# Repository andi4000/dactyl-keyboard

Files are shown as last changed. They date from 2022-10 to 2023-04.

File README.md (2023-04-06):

# Andi4000 6x7 Dactyl-ManuForm Fork

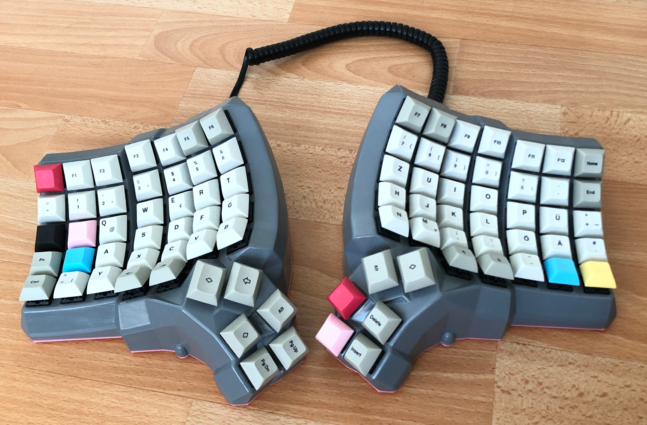
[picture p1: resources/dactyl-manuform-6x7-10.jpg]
Dactyl Manuform 6x7 ISO-DE


Pictured is the finished build with (close to) ISO-DE Layout, with DSA Profile
Keycaps from YMDK, and some blank 1U keycaps.

[Click here](#firmware) for the QMK Firmware for this layout.

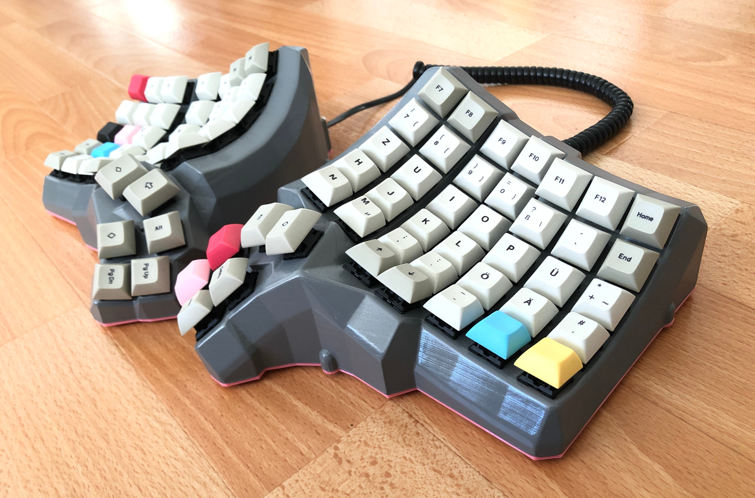
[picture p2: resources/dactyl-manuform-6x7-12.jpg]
Dactyl Manuform 6x7 ISO-DE


## TODO
- reduce heat insert diameter

## Differences
- 6x7 Layout. Coming from TKL ISO Layout, I am too lazy to use layers and learn
  a new layout. I also need dedicated F-Keys.
- No Wire Post
- Mount for [Delock Cable USB 2.0 Micro-B Female Panel-Mount](https://www.delock.com/produkt/85245/merkmale.html)
- Flipped RJ9 mount, so that the cable clip will end up on the upper side
- New Promicro Mount

See [right.stl](things/right.stl) for preview.

## FDM 3D-Print Setup
- I use Ultimaker Cura (v5.1.1) as slicer, with following settings
    - 0.2mm layer height
    - (**Important**) Support Structure: Tree --> extremely easier to remove
      compared to normal
    - 10% Infill
    - 10mm Brim
- Printer: stock Sovol SV02 with heated bed, Esun PLA with 205°C nozzle temp 
  and 60°C bed temp.
- PVA glue (UHU Stic) applied to the bed, especially on the brim and sidewalls
  area because they tend to warp, which is a common (big) print issue.
- How to know where the brim and side wall will go? Start print and stop when
  the outer brim is printed. That would be the boundaries. I applied generous
  amount of PVA glue there.
- Once the print reaches ca. Z=10mm, if warping is not present, print is more
  likely to be succeeded, w.r.t. warping.
- Be careful on removing support structure around the Promicro mount. Make sure
  you know how it should look like without the support. See `right.stl`.

## Assembly
For 6x7 you need following items:
- 86 Cherry-MX (or compatible) Switches
- 82 1U Keycaps. I use DSA profile keycaps. Cherry profile are reported to also
  work.
- 4 1U or 1.25U Keycaps for the upper thumb
- M3 Heat Inserts, at least 10 pcs.
- M3x5 countersink screws, at least 10 pcs.

Wired and (almost fully) assembled left side:
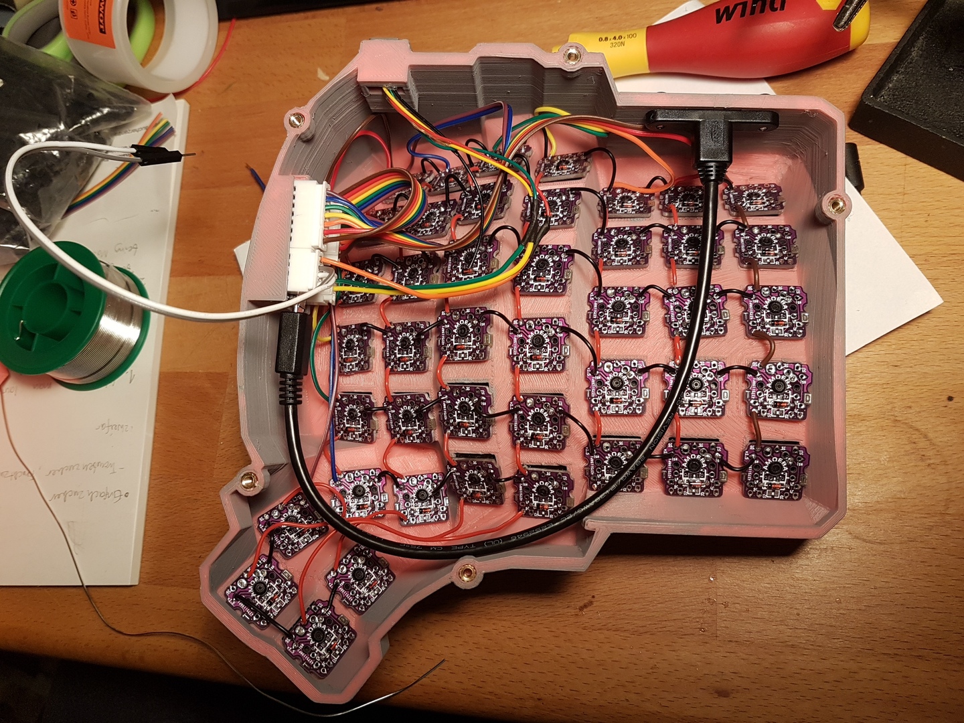
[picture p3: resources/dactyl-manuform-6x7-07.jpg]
wired left side


What really helped during the assembly was to have and use following:
- [Amoeba single-switch PCB](https://deskthority.net/viewtopic.php?t=11420) from
  a local vendor. I bought 100 pcs. with some spares just in case I messed up.
- A good soldering iron. I used [Ersa C25 25W](https://www.ersa-shop.com/ersa-l%C3%B6tkolben-multitip-230v-p-2787.html).
  I went through two cheap soldering irons, both end up with broken tip and
  subpar results. Also a metal solder tip cleaner.
- Single-core jumper wires. I used wires with 0.2 sq. mm cross section. It's
  stiff compared to wires with multi-core, which make the PCBs to stay in place
  before soldering.
- Multimeter to do continuity check. Cheap one will do.

Additionally I also use XH-Type connector at the ProMicro as idiot-proofing.

## Build Photos
<details>
<summary>Finished 24h-long print.</summary>
"Tree" support structure really makes removing supports easier.

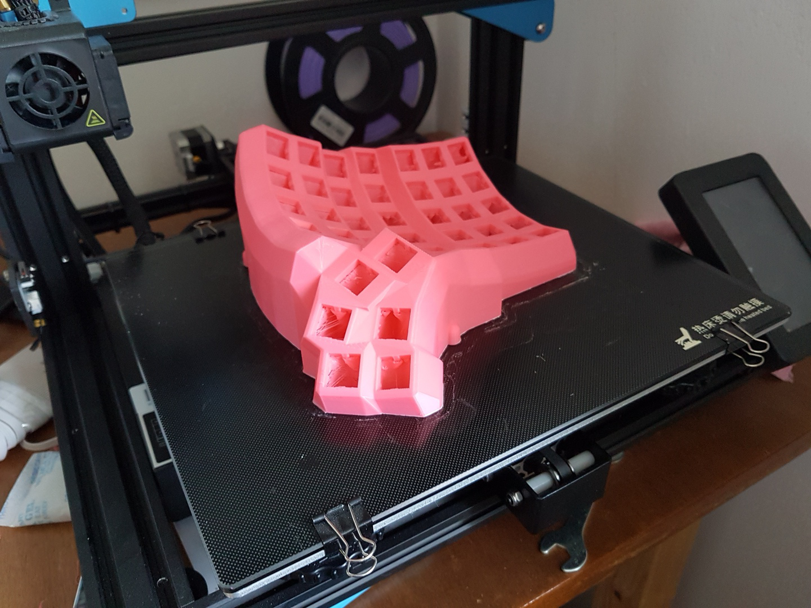
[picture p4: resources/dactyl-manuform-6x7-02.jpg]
fresh out of the oven

</details>

<details>
<summary>Sanded, primered, painted, clear coat.</summary>

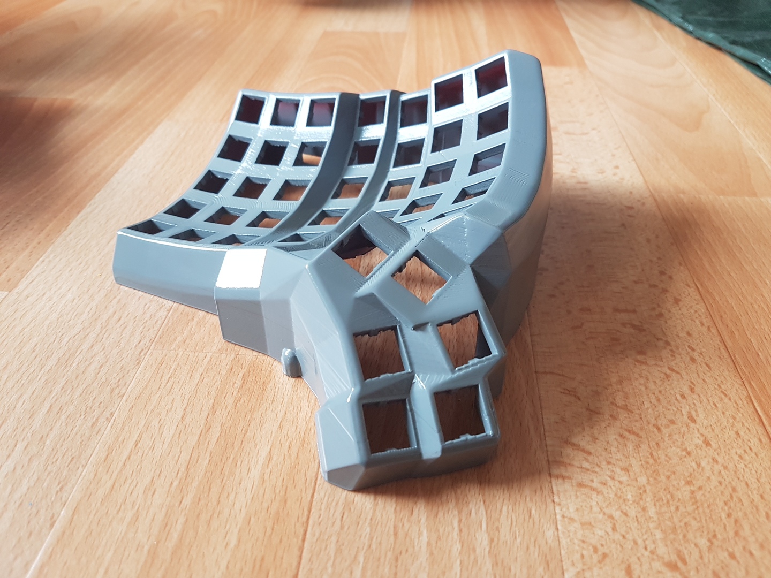
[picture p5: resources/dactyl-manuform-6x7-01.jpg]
sanded and painted

</details>

<details>
<summary>Continuity check after soldering diodes.</summary>
Easier if you do this in batch of e.g. 10 PCBs

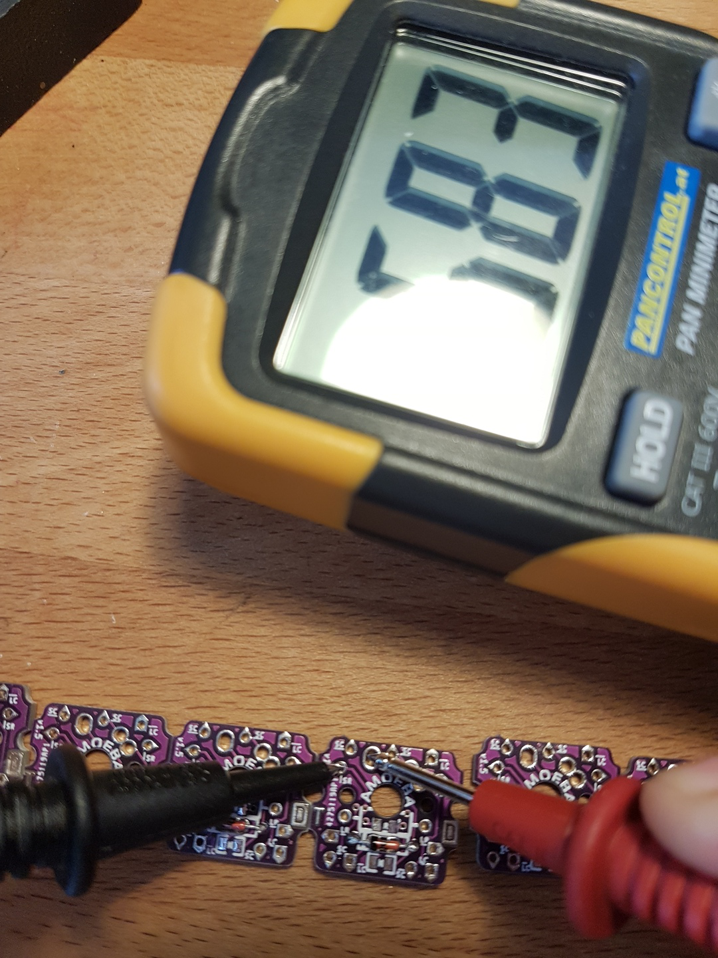
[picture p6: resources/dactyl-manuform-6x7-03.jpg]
continuity check

</details>

<details>
<summary>Wiring harness with Amoeba PCB for the left side.</summary>
With XH-Connectors for the rows and columns

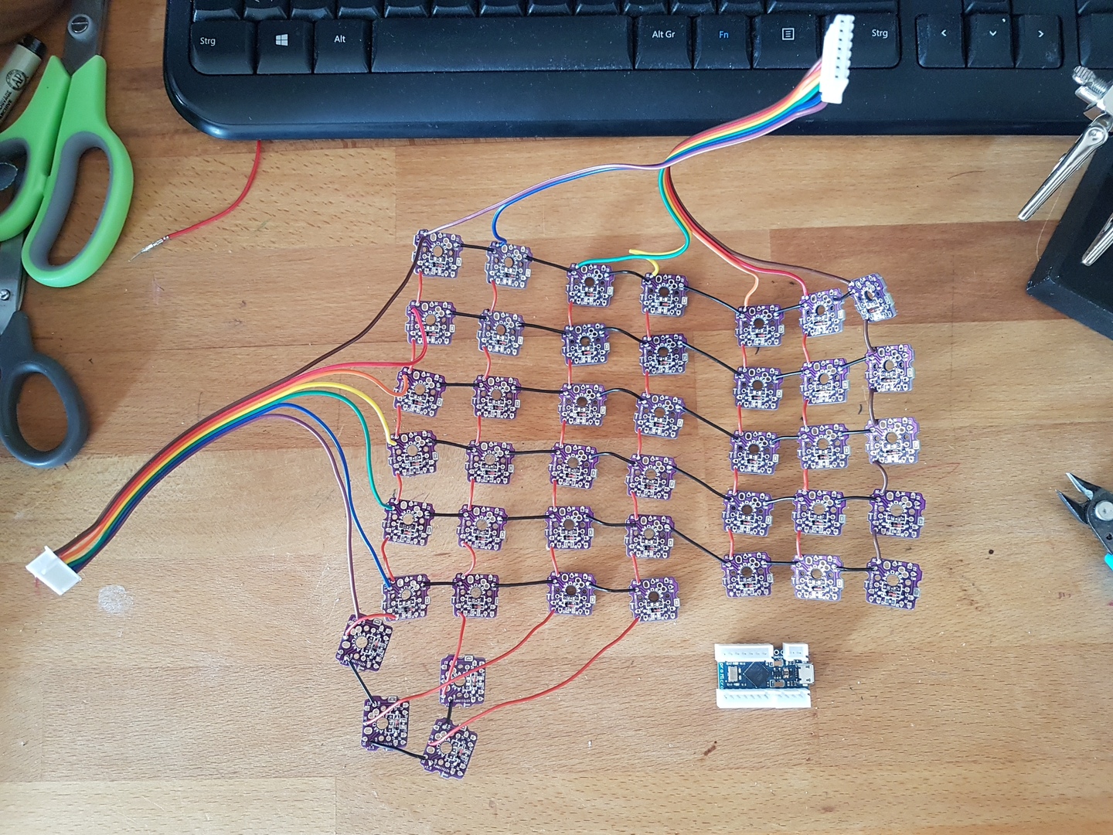
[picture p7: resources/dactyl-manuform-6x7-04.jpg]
wiring left with XH connector


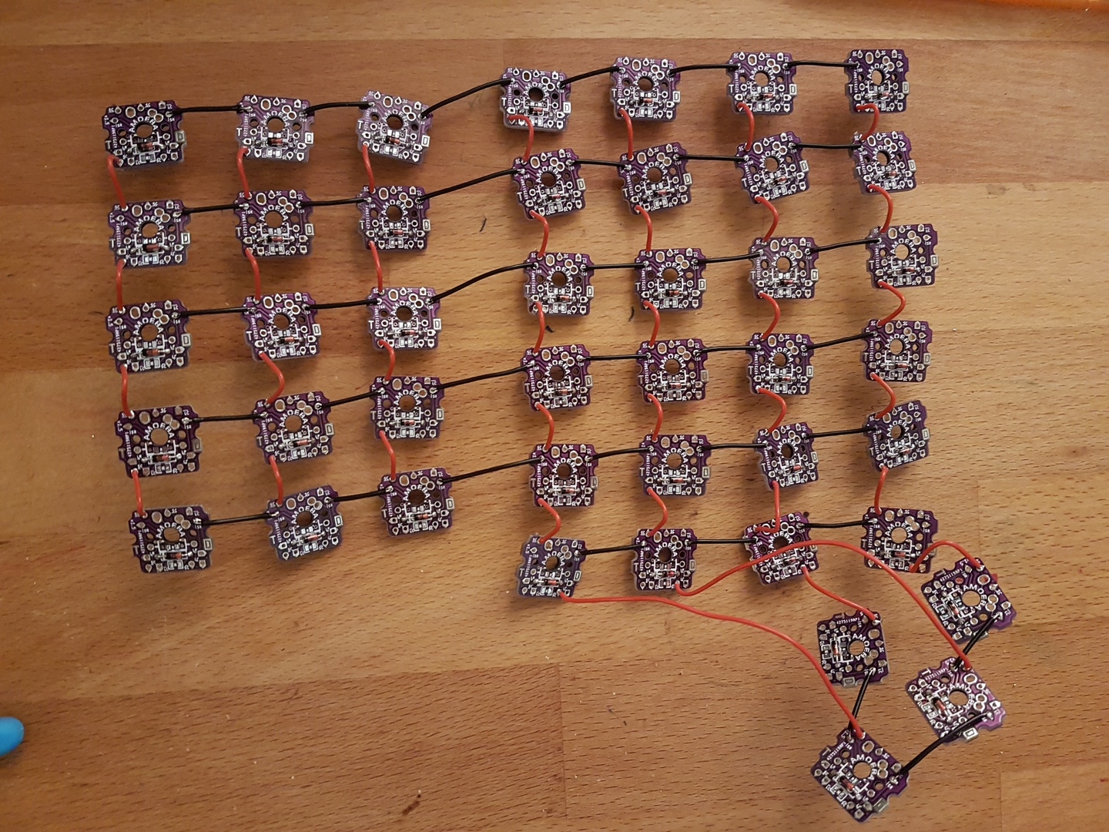
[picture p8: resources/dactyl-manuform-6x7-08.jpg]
wiring left

</details>

<details>
<summary>Mounted wiring harness for the left side.</summary>
Soldering the top left (the deepest point) was really difficult.
I found it to be easier to first remove the switch, put PCB on position,
then carefully insert the switch back.

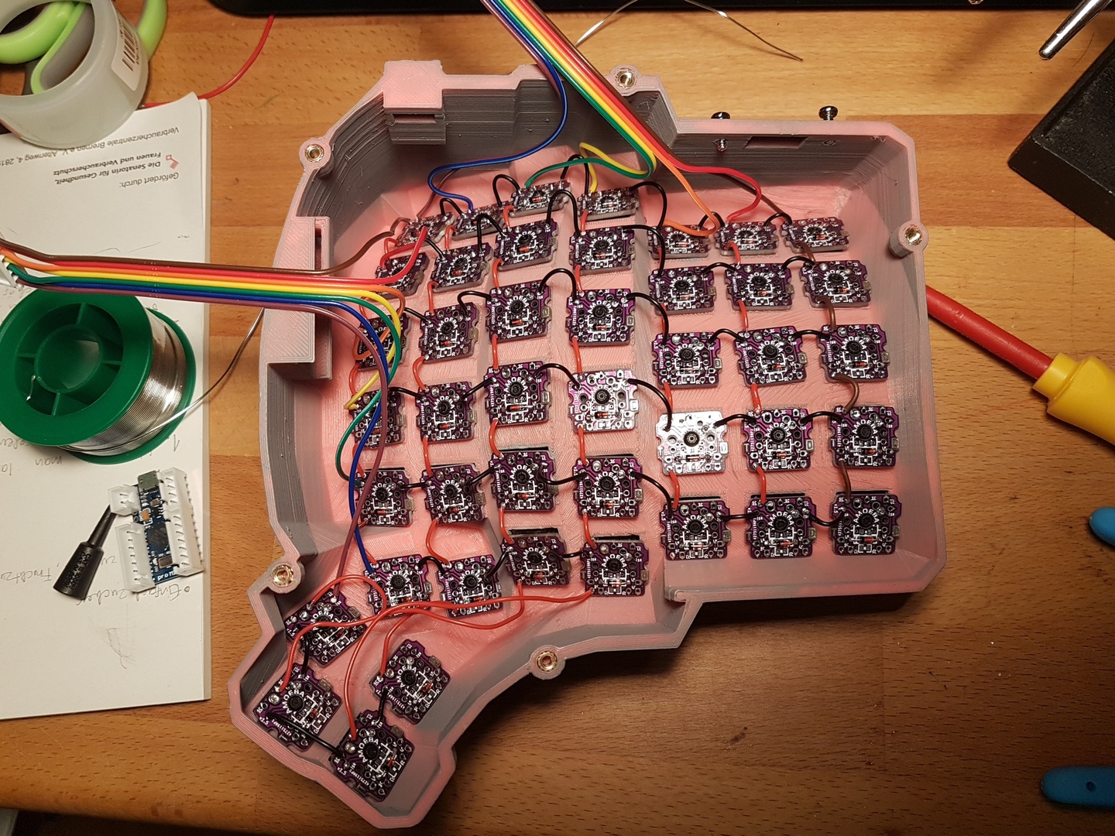
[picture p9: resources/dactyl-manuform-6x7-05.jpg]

</details>

<details>
<summary>Close up of the mounted wiring harness for the left side.</summary>
Bokeh!

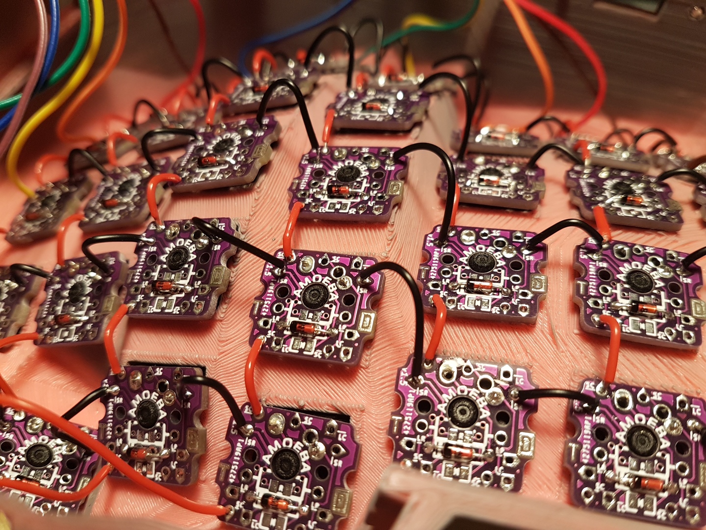
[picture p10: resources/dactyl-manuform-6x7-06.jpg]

</details>

<details>
<summary>Wiring harness for the right side.</summary>
It was a very sunny day

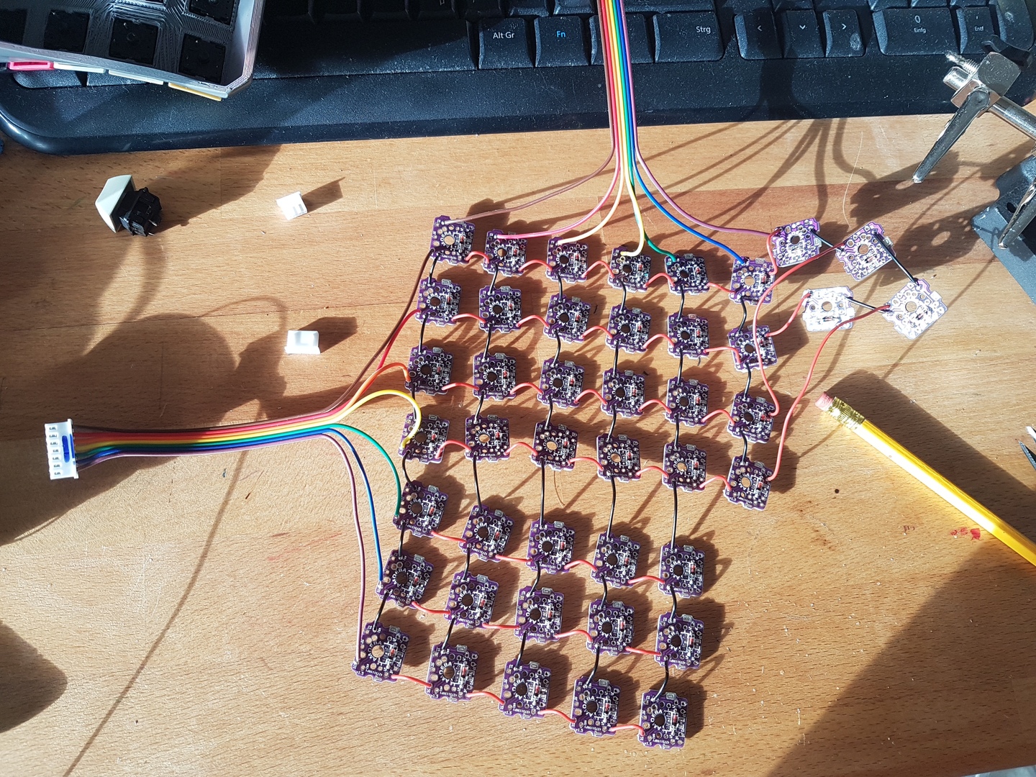
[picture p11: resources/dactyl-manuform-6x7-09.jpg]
wiring right

</details>

<details>
<summary>Finished!</summary>

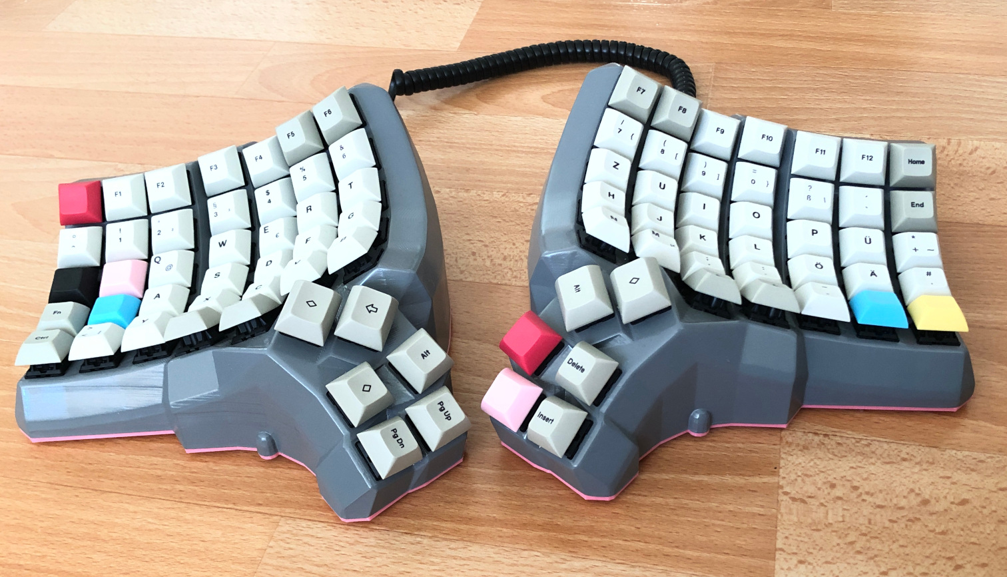
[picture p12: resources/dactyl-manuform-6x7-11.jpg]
Done

</details>

## Firmware

For firmware flashing please refer to this page on QMK: [qmk_firmware for 6x7 Dactyl Manuform ISO-DE](https://github.com/qmk/qmk_firmware/tree/master/keyboards/handwired/dactyl_manuform/6x7/keymaps/iso-de)

## License

The source code for generating the models (everything excluding the [things/](things/) and [resources/](resources/) directories is distributed under the [GNU AFFERO GENERAL PUBLIC LICENSE Version 3](LICENSE).  The generated models and PCB designs are distributed under the [Creative Commons Attribution-NonCommercial-ShareAlike License Version 3.0](LICENSE-models).

## Original Readme
[README.orig.md](README.orig.md)

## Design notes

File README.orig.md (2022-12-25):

# The Dactyl-ManuForm Keyboard
This is a fork of the [Dactyl](https://github.com/adereth/dactyl-keyboard), a parameterized, split-hand, concave, columnar, ergonomic keyboard.

Imgur

The main change is that the thumb cluster was adapted from the [ManuForm keyboard](https://github.com/jeffgran/ManuForm) ([geekhack](https://geekhack.org/index.php?topic=46015.0)). The walls were changed to just drop to the floor. The keyboard is paramaterized to allow adjusting the following: 

* Rows: 4 - 6 
* Columns: 5 and up
* Row curvature
* Column curvature
* Row tilt (tenting)
* Column tilt
* Column offsets
* Height

I built a 4x5 version (40% size) for myself. The default has a bit more tenting than the Dactyl. See the following model files for configurations that may be most common:

* [40% size, (4x5)](https://github.com/tshort/dactyl-keyboard/blob/master/things/right-4x5.stl)
* [60% size, (5x6)](https://github.com/tshort/dactyl-keyboard/blob/master/things/right-5x6.stl)

## Assembly

### Generating a Design

**Setting up the Clojure environment**
* [Install the Clojure runtime](https://clojure.org)
* [Install the Leiningen project manager](http://leiningen.org/)
* [Install OpenSCAD](http://www.openscad.org/)

**Generating the design**
* Run `lein repl`
* Load the file `(load-file "src/dactyl_keyboard/dactyl.clj")`
* This will regenerate the `things/*.scad` files
* Use OpenSCAD to open a `.scad` file.
* Make changes to design, repeat `load-file`, OpenSCAD will watch for changes and rerender.
* When done, use OpenSCAD to export STL files

**Tips**
* [Some other ways to evaluate the clojure design file](http://stackoverflow.com/a/28213489)
* [Example designing with clojure](http://adereth.github.io/blog/2014/04/09/3d-printing-with-clojure/)

### Printing
Pregenerated STL files are available in the [things/](things/) directory. 
When a model is generated, it also generates a `.scad` model for a bottom plate. 
This can be exported to a DXF file in OpenSCAD.
The [things/](things/) directory also has DXF files for the bottom plate.
When laser cut, some of the inside cuts will need to be removed. 

This model can be tricky to print. 
It's wide, so I've had problems with PLA on a Makerbot with edges warping. 
This can cause the printer to think its head is jammed. 
Even if it successfully prints, warping can cause problems. 
On one print, the RJ-9 holder was squished, so I had to cut down my connector to fit.

If printed at Shapeways or other professional shops, I would not expect such problems. 

### Thingiverse

[The 4x5 STL left/right pair](https://www.thingiverse.com/thing:2349390) from the [things/](things/) directory is in the thingiverse for public printing

### Wiring

Here are materials I used for wiring.

* Two Arduino Pro Micros
* [Heat-set inserts](https://www.mcmaster.com/#94180a331/=16yfrx1)
* [M3 wafer-head screws, 5mm](http://www.metricscrews.us/index.php?main_page=product_info&cPath=155_185&products_id=455)
* [Copper tape](https://www.amazon.com/gp/product/B009KB86BU)
* [#32 magnet wire](https://www.amazon.com/gp/product/B00LV909HI)
* [#30 wire](https://www.amazon.com/gp/product/B00GWFECWO)
* [3-mm cast acrylic](http://www.mcmaster.com/#acrylic/=144mfom)
* [Veroboard stripboard](https://www.amazon.com/gp/product/B008CPVMMU)
* [1N4148 diodes](https://www.amazon.com/gp/product/B00LQPY0Y0)
* [Female RJ-9 connectors](https://www.amazon.com/gp/product/B01HU7BVDU/)

I wired one half using the traditional approach of using the legs of a diode to form the row connections. 
(I'm not great at soldering, so this was challenging for me.)
For this side, I used magnet wire to wire columns. That worked okay. 
The magnet wire is small enough, it wants to move around, and it's hard to tell if you have a good connection.

Imgur

For another half, I used stripboard for the row connections. 
This allowed me to presolder all of the diodes. 
Then, I hot-glued this in place and finished the soldering of the other diode ends. 
I like this approach quite a lot. 
Connections for the diodes were much easier with one end fixed down. 
On this half, I also used copper tape to connect columns. 
This worked a bit better than the magnet wire for me. 
For a future version, I may try just bare tinned copper wire for columns (something like #20). 
With the stripboard, it's pretty easy keeping row and column connections separate.

Imgur

Note that a telephone handset cable has leads that are reversed, so take this into account when connecting these leads to the controller.

The 3D printed part is the main keyboard. 
You can attach a bottom plate with screws. 
The case has holes for heat-set inserts designed to hold 3- to 6-mm long M3 screws. 
Then, I used wafer-head screws to connect a bottom plate. 
If wires aren't dangling, a bottom plate may not be needed. 
You need something on the bottom to keep the keyboard from sliding around. 
Without a plate, you could use a rubber pad, or you could dip the bottom of the keyboard in PlastiDip.

For more photos of the first complete wiring of v0.4, see [Imgur](http://imgur.com/a/v9eIO).

This is how the rows/columns wire to the keys and the ProMicro
Wire Diagram

#### Alternative row-driven wiring diagram for ProMicro:

NOTE: you also make sure the firmware is set up correctly (ex: change row pins with col pins)

Left Wire Diagram

Left Wire Diagram

### Firmware

Firmware goes hand in hand with how you wire the circuit. 
I adapted the QMK firmware [here](https://github.com/tshort/qmk_firmware/tree/master/keyboards/dactyl-manuform). 
This allows each side to work separately or together. 
This site also shows connections for the Arduino Pro Micro controllers.

## License

Copyright © 2015-2017 Matthew Adereth and Tom Short

The source code for generating the models (everything excluding the [things/](things/) and [resources/](resources/) directories is distributed under the [GNU AFFERO GENERAL PUBLIC LICENSE Version 3](LICENSE).  The generated models and PCB designs are distributed under the [Creative Commons Attribution-NonCommercial-ShareAlike License Version 3.0](LICENSE-models).

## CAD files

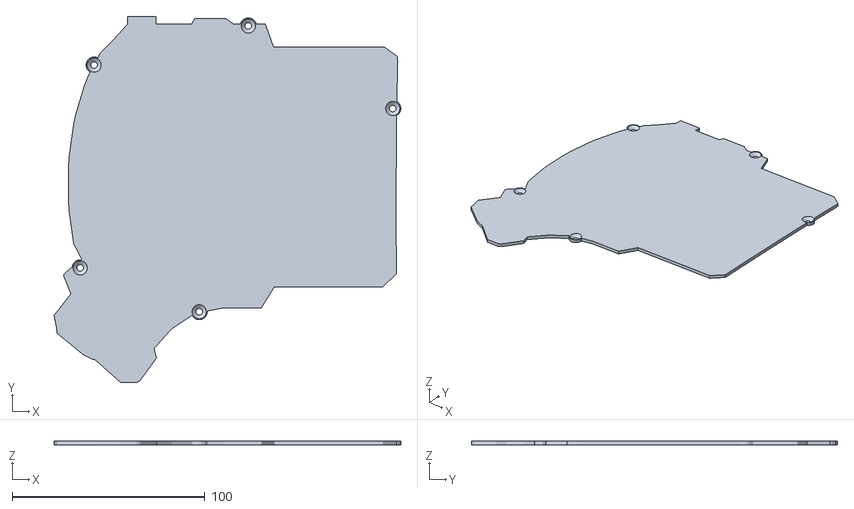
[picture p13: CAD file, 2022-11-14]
things/right-plate-6x7.stl
180.0 x 189.9 x 2.00

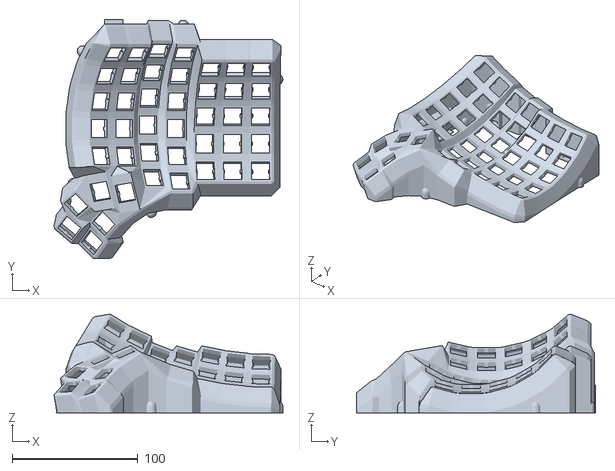
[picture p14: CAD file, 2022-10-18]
things/right.stl
181.9 x 190.2 x 78.5

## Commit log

2022-10-08 remove original things
    [left-4x5.stl, left-4x6.stl, left-5x6.stl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]
2022-10-08 remove wire post
2022-10-14 replace usb hole with usb panel mount
2022-10-15 flip rj9 holder upside-down
    so that the cable clips will be on the upper side
2022-10-15 add scad and stl file for 6x7 layout
    [left.stl, right.stl]
2022-10-16 removed left.stl because its just a mirrored right.stl
    [left.stl]
2022-10-16 bugfix: screw hole size
2022-10-18 adjust promicro holder to fit XH connectors
2022-10-18 update scad and stl files
    with:
    - fixed usb panel mount screw hole size
    - bigger promicro holder with XH connectors
    [right.stl]
2022-11-14 add right plate svg
2022-11-14 add STL for right-plate
    prepared in Adobe Fusion 360 from right-plate.svg
    [right-plate-6x7.stl]
2022-12-25 add glamour shot of the wiring harness
